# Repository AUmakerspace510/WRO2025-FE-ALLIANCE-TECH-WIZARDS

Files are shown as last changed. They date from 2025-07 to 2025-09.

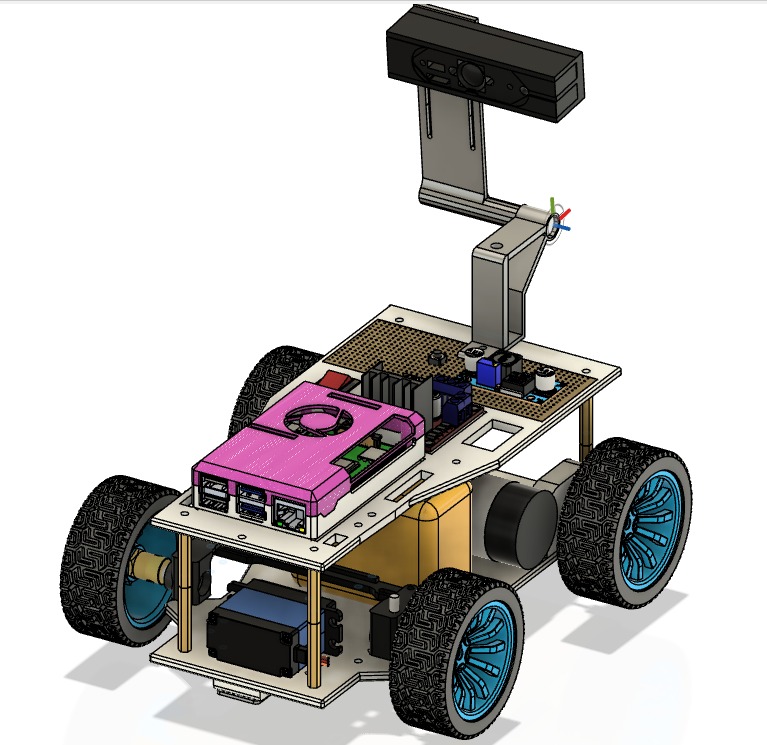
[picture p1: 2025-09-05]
Engineering Factor/3D Design Images/Isometric View.jpg

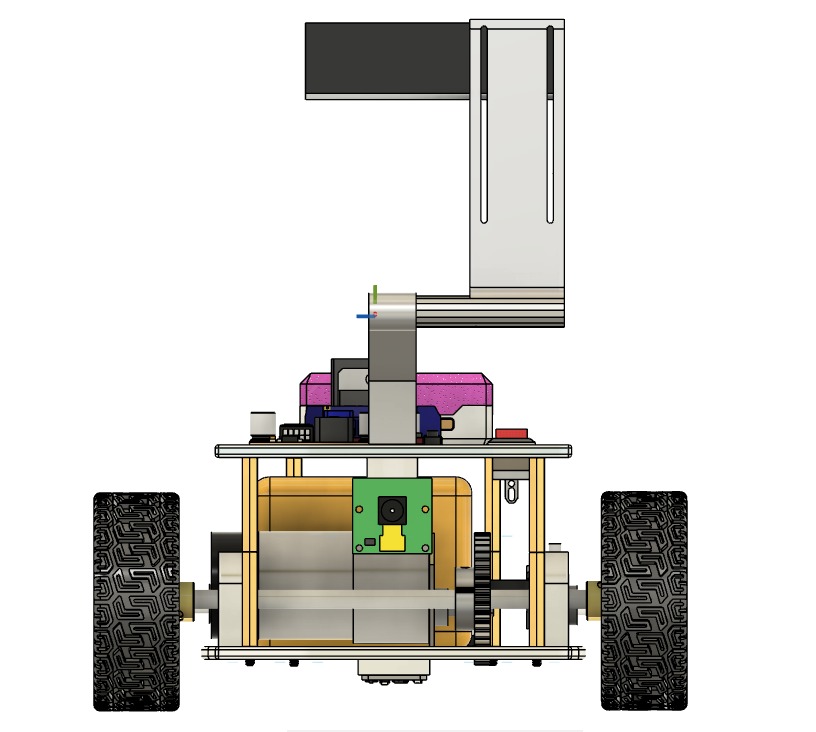
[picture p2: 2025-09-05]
Engineering Factor/3D Design Images/Back View.jpg

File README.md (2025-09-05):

Engineering materials
====

This repository contains engineering materials of a self-driven vehicle's model participating in the WRO Future Engineers competition in the season 202.

## Content

* `t-photos` contains 2 photos of the team (an official one and one funny photo with all team members)
* `v-photos` contains 6 photos of the vehicle (from every side, from top and bottom)
* `video` contains the video.md file with the link to a video where driving demonstration exists
* `schemes` contains one or several schematic diagrams in form of JPEG, PNG or PDF of the electromechanical components illustrating all the elements (electronic components and motors) used in the vehicle and how they connect to each other.
* `src` contains code of control software for all components which were programmed to participate in the competition
* `models` is for the files for models used by 3D printers, laser cutting machines and CNC machines to produce the vehicle elements. If there is nothing to add to this location, the directory can be removed.
* `other` is for other files which can be used to understand how to prepare the vehicle for the competition. It may include documentation how to connect to a SBC/SBM and upload files there, datasets, hardware specifications, communication protocols descriptions etc. If there is nothing to add to this location, the directory can be removed.

<<<<<<< HEAD
=======
_This part must be filled by participants with the technical clarifications about the code: which modules the code consists of, how they are related to the electromechanical components of the vehicle, and what is the process to build/compile/upload the code to the vehicle’s controllers._

## How to prepare the repo based on the template

_Remove this section before the first commit to the repository_

1. Clone this repo by using the `git clone` functionality.
2. Remove `.git` directory
3. [Initialize a new public repository on GitHub](https://github.com/new) by following instructions from "create a new repository on the command line" section (appeared after pressing "Create repository" button).
## readme update
>>>>>>> a575a0db0843b93a4ccf974dce975ff79b570c73

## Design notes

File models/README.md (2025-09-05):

```
# models

This directory contains all the files related to the 3D models and designs for the project. It is organized into several sub-folders for easy navigation and access to different types of files.

## Directory Structure

- `models/`
  - `.stl Files/`: Contains the Stereolithography (.stl) files for 3D printing. These files are the final, ready-to-print models.
  - `3D Design Images/`: Includes various rendered images of the 3D models from different perspectives, as well as a documentation file. These are useful for visualizing the complete design.
  - `parts_dimensions/`: Houses detailed dimensional drawings and images for individual parts. This is crucial for manufacturing, assembly, and reference.

## Contents

### .stl Files

This folder holds the 3D printable files.

- **`WRO_CAMERA HOLDER BASE.stl`**: The base part for the camera holder assembly.
- **`WRO_CAMERA HOLDER.stl`**: The main body of the camera holder, which attaches to the base.
- **`WRO_LOWER CHASIS.stl`**: The bottom section of the robot's chassis.
- **`WRO_UPPER CHASIS.stl`**: The top section of the robot's chassis.

### 3D Design Images

This folder contains rendered images of the complete 3D design.

- **`3D Design Images.docx`**: A document that may contain additional details, descriptions, or a compilation of the images.
- **`Back View.jpg`**: A view of the model from the back.
- **`Camera Holder Isometric View.jpg`**: An isometric view specifically of the camera holder.
- **`Front View.jpg`**: A view of the model from the front.
- **`Isometric View with Labelling.jpg`**: An isometric view with key components labeled for identification.
- **`Isometric View.jpg`**: A general isometric view of the model.
- **`Left View.jpg`**: A view of the model from the left side.
- **`Right View.jpg`**: A view of the model from the right side.
- **`Top Right View.jpg`**: A top-down, slightly angled view of the model.

### parts_dimensions

This folder provides detailed dimensional drawings and images for the individual parts, organized by component.

- **`lower_chassis/`**:
  - `1.png` through `8.png`: A series of images showing various dimensions and features of the lower chassis.
  - `LOWER.png`: A general dimensional drawing of the lower chassis.
  - `PART_LOWER.jpg`: An image of the lower chassis part.

- **`upper_chassis/`**:
  - `1.png` through `7.png` (with `5.png` and `6.png` potentially missing): A series of images showing various dimensions and features of the upper chassis.
  - `PART-11.png`: An additional part-specific image for the upper chassis.

- **`CAMERA_HOLDER.png`**: A dimensional drawing or image for the camera holder part.

---

This README is a general overview. For specific details on each file, refer to its file name and location within the folder structure.
```

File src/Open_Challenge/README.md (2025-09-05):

# WRO2025 FE ALLIANCE TECH WIZARDS - Autonomous Raspberry Pi Robot

This repository contains three core Python files that together enable a Raspberry Pi-powered robot to autonomously follow colored stripes, detect walls, make turns, and stop after completing its course. Below you’ll find detailed documentation for each file.

---

## 1. `masks.py`

### Purpose
Defines color masks for use in image processing. These are LAB color space ranges which help the robot identify different colored stripes (magenta, red, green, blue, orange) and walls (black) in the environment.

### How It Works
- Each mask is a list with two NumPy arrays: the lower and upper bounds for LAB color segmentation.
- These masks are imported in other files and used to isolate specific colors in images captured by the camera.

### Example Usage
Used in the `find_contours` function in `functions.py` and the main loop in `main.py` to detect colored stripes and walls.

### File Reference
```python
import numpy as np

rMagenta = [np.array([22, 150, 50], np.uint8), np.array([200, 200, 150], np.uint8)]
rRed     = [np.array([0, 150, 120], np.uint8), np.array([255, 220, 180], np.uint8)]
rGreen   = [np.array([0, 50, 0], np.uint8), np.array([255, 120, 255], np.uint8)]
rBlue    = [np.array([0, 120, 60], np.uint8), np.array([255, 160, 120], np.uint8)]
rOrange  = [np.array([0, 117, 150], np.uint8), np.array([255, 200, 200], np.uint8)]
rBlack   = [np.array([0, 105, 105], np.uint8), np.array([80, 151, 151], np.uint8)]

lotType = "light"  # 0 for dark purple, 1 for magenta (not used in main code)
```

---

## 2. `functions.py`

### Purpose
Contains all hardware control and image processing functions. This file abstracts GPIO operations and OpenCV image processing into reusable functions.

### Key Functions

- **GPIO Setup:** Configures motor and servo pins, establishes PWM channels.
- **set_motor(speed):** Controls direction and speed of DC motor using L298N.
- **set_servo_angle(angle):** Sets steering angle for the servo motor.
- **write(value):** Unified interface for controlling either steering angle or motor speed.
- **multi_write(sequence):** Executes a list of actions (angles, speeds, delays).
- **stop_car():** Safely stops the robot and resets steering.
- **move_backward_with_mirror(forward_angle, duration, speed):** Reverses with mirrored steering (for advanced maneuvers).
- **display_roi(img, ROIs, color):** Draws rectangles for specified regions of interest (ROIs) on the image, useful for debugging.
- **find_contours(img_lab, lab_range, ROI):** Segments a region of the image for a specific color and finds contours.
- **max_contour(contours, ROI):** Returns area and position of the largest contour found in an ROI.
- **display_variables(variables):** Prints debug information about main variables (e.g., detected wall areas).

### How It Works
- The robot’s hardware (motors/servo) are controlled indirectly by calling these functions from the main loop.
- Image processing functions enable stripe/wall detection, which informs the robot's navigation logic.

### Example Usage
Used by `main.py` to execute movement, steering, and image analysis every frame.

### File Reference
```python
# Example: set_motor(50) moves forward, set_servo_angle(110) steers straight.
# Example: find_contours(img_lab, rBlack, ROI1) gets contours for black walls in left ROI.
```

---

## 3. `main.py`

### Purpose
The main execution file. This script launches the robot’s operational loop: waiting for button press, initializing camera and hardware, detecting stripes and walls, handling turns, counting stripes, and stopping after finishing the course.

### How It Works

1. **Startup:**
   - Waits for the physical button press to start.
   - Initializes camera and sets capture parameters.

2. **ROIs (Regions of Interest):**
   - Defines five ROIs for focused color and wall detection:
     - ROI1: Bottom left (left wall)
     - ROI2: Bottom right (right wall)
     - ROI3: Center (stripe detection)
     - ROI4: Far left (orange turn trigger)
     - ROI5: Far right (blue turn trigger)

3. **Main Loop:**
   - Captures frame, processes in LAB color space.
   - Detects contours for walls and stripes using masks from `masks.py` and functions from `functions.py`.
   - Uses the area of detected contours to maintain wall-following via PID steering logic.
   - Counts stripes (with debounce) and stops after 12 stripes.
   - Handles turns when wall is lost in ROI4/ROI5 (depending on detected color).
   - Displays debug info and stops on user command or course completion.

### Example Usage
Run this file to start the robot after wiring and camera setup.

### File Reference
```python
from functions import *
from masks import rOrange, rBlack, rBlue

# Main loop:
# while True:
#     ret, img = cap.read()
#     img_lab = cv2.cvtColor(img, cv2.COLOR_BGR2Lab)
#     cListLeft = find_contours(img_lab, rBlack, ROI2)
#     ... (see full file for details)
```

---

## Additional Notes

- **Dependencies:** Make sure to install `numpy`, `RPi.GPIO`, and `opencv-python` on your Raspberry Pi.
- **Hardware:** Connect L298N motor driver and a servo as per pin definitions in `functions.py`.
- **Camera:** Any USB webcam compatible with OpenCV should work.
- **Debugging:** Enable `debug = True` in `main.py` to visualize ROIs and variables via OpenCV window.
- **Safety:** The `stop_car()` function is called on exit or after finishing the course to ensure the robot halts safely.

---

## Quick Start

1. Wire up your robot according to the pin definitions in `functions.py`.
2. Place all three files (`masks.py`, `functions.py`, `main.py`) in the same directory.
3. Run `main.py` on your Raspberry Pi.
4. Press the button to start the robot. Watch it follow colored stripes and walls, count stripes, make turns, and stop after the course!

---

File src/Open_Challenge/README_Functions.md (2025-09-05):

# `functions.py` — Hardware and Vision Utilities for Autonomous Robot

This file provides all the core hardware control and image processing functions for your Raspberry Pi robot car.  
It abstracts GPIO operations, PWM setup, DC motor and steering servo commands, and encapsulates reusable vision functions for finding colored contours and displaying debug overlays.

---

## Main Sections

### 1. GPIO and PWM Setup
- Initializes the Raspberry Pi GPIO in BCM mode.
- Sets up output pins for the L298N motor driver (IN1, IN2, ENA) and the servo (SERVO_PIN).
- Configures PWM channels for motor speed and servo position.

---

### 2. Motor Control Functions

#### `set_motor(speed)`
- Controls motor direction and speed via L298N.
- `speed` range: -100 (full reverse) to +100 (full forward), 0 stops.
- Used for every movement or stop command.

#### `CENTER_ANGLE`, `MIN_ANGLE`, `MAX_ANGLE`
- Constants for steering servo position.
- `CENTER_ANGLE` is straight ahead, `MIN_ANGLE` is full left, `MAX_ANGLE` is full right.

#### `set_servo_angle(angle)`
- Sets the servo steering angle, clamped between allowed bounds.
- Converts angle to a PWM duty cycle for accurate positioning.

---

### 3. High-Level Control Functions

#### `write(value)`
- Unified interface for controlling either steering or motor speed.
- If value is in [60,160], sets servo; if in [1000,2000], sets motor speed.

#### `multi_write(sequence)`
- Executes a sequence of actions: steering angles, speeds, or sleep delays.
- Useful for initialization or executing maneuvers.

#### `stop_car()`
- Stops all movement, centers steering, and closes OpenCV windows.
- Called on exit or emergency stop.

#### `move_backward_with_mirror(forward_angle, duration=1, speed=50)`
- Moves the car backward, steering mirrored relative to the last forward angle.
- For advanced reversing maneuvers.

---

### 4. Image Processing Functions

#### `display_roi(img, ROIs, color)`
- Draws rectangles (ROIs) on the image for visualizing detection zones.
- Used for debugging and live feedback in OpenCV window.

#### `find_contours(img_lab, lab_range, ROI)`
- Crops the specified ROI from the LAB image.
- Applies LAB color masking, erodes/dilates to reduce noise.
- Finds and returns contours matching the color mask.

#### `max_contour(contours, ROI)`
- Selects the largest contour in a region, computes area and position.
- Returns `[maxArea, maxX, maxY, mCnt]` for use in steering and wall detection.

#### `display_variables(variables)`
- Prints key debug information (areas, angles, detected colors, etc.) to the console.
- Overwrites previous values for real-time updates.

---

## How This File Is Used

- **Imported in `main.py`** for all hardware and vision operations.
- **Keeps main loop clean:** Complex hardware logic and image analysis are abstracted away for clarity and reuse.
- **Facilitates debugging:** Functions like `display_roi` and `display_variables` enable easy real-time monitoring.

---

## Typical Usage Example

```python
from functions import *

# Set motor speed and direction
set_motor(80)  # Move forward

# Set steering angle
set_servo_angle(110)  # Straight

# Mask and find contours in a camera image
contours = find_contours(img_lab, rOrange, ROI3)
area, x, y, cnt = max_contour(contours, ROI3)

# Stop the car
stop_car()
```

---

## Troubleshooting

- **Servo or motor not responding:** Check GPIO pin assignment and connections.
- **Vision functions not finding contours:** Ensure correct LAB mask values and ROI placement; tune masks with your LAB mask tuner tool.
- **Debugging:** Use `display_roi` and `display_variables` to monitor real-time system state.

---

## References

- [RPi.GPIO documentation](https://sourceforge.net/p/raspberry-gpio-python/wiki/Home/)
- [OpenCV Python reference](https://docs.opencv.org/)
- [L298N Motor Driver](https://www.electronicwings.com/nodemcu/l298n-motor-driver)
- [Servo PWM basics](https://www.raspberrypi-spy.co.uk/2013/07/using-a-servo-with-the-raspberry-pi/)

---

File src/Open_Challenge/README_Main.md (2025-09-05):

# Main Program (`main.py`) — Detailed Documentation

`main.py` contains the main execution loop for the autonomous robot, orchestrating image processing, hardware control, stripe counting, PID steering, and turn handling.  
This file is the entry point for your robot’s run.

---

## Overview of Main Blocks

### 1. **Startup & Initialization**

- **Button Press to Start**  
  Waits for the user to press a physical button (GPIO 26, active LOW) before starting. This ensures safe, controlled startup.

- **Camera Initialization**  
  Sets up the USB camera at 1280x720 resolution, 30 FPS.  
  Checks if the camera opens correctly; exits if not.

---

### 2. **Region of Interest (ROI) Setup**

Defines 5 ROIs (`ROI1` to `ROI5`) as rectangles `[x1, y1, x2, y2]`:
- **ROI1**: Bottom left — left wall detection
- **ROI2**: Bottom right — right wall detection
- **ROI3**: Center — stripe detection
- **ROI4**: Far left — used for orange turn logic
- **ROI5**: Far right — used for blue turn logic

**Purpose:**  
ROIs allow focused contour detection, increasing accuracy and reducing computational load.

---

### 3. **Control Variables**

- **PID parameters:**  
  - `kp` (proportional gain): Controls how strongly the robot reacts to wall area difference.
  - `kd` (derivative gain): Dampens oscillations based on change in area difference.
- **Steering constants:**  
  - `straightConst`: Angle for straight driving.
  - `sharpLeft`, `sharpRight`, `maxLeft`, `maxRight`: Boundaries for sharp turns.
- **Speed:**  
  - Constant value (`speed = 1500`) for motor PWM.

- **Course color detection:**  
  - `activeColor`: Set to `"orange"` or `"blue"` on first detected stripe.
  - `colorCount`: Tracks the number of stripes detected.
  - `debounceSec`: Ensures stripes aren’t double-counted.

---

### 4. **Main Loop — Frame-by-Frame Workflow**

#### a. **Image Capture and Preprocessing**
- Captures a frame.
- Converts frame to LAB color space (more robust to lighting).
- Applies Gaussian blur to reduce noise.

#### b. **Contour Detection**
- Uses functions from `functions.py`:
  - `find_contours()` called for each relevant ROI and color mask.
  - `max_contour()` retrieves area and position for the largest contour.

#### c. **Course Color Selection & Stripe Counting**
- If `activeColor` is not set, assigns based on first detected stripe.
- Stripe count (`colorCount`) incremented only if sufficient time has passed since last detection (`debounceSec` logic).

#### d. **Stopping Logic**
- When 12 stripes detected, robot waits a set period (e.g., 4 seconds) then calls `stop_car()` and exits the loop.

#### e. **Turn Handling**
- **Blue Course:**  
  If left wall is lost in ROI4, rotates left (steers to minimum angle) until left wall is detected in ROI1.
- **Orange Course:**  
  If right wall is lost in ROI5, rotates right (steers to maximum angle) until right wall is detected in ROI2.
- **Purpose:**  
  Allows robot to reliably handle sharp turns and intersections.

#### f. **PID Steering Control**
- Calculates `aDiff = rightArea - leftArea` (difference in wall detection).
- **Angle calculation:**  
  `angle = straightConst + aDiff * kp + (aDiff - prevDiff) * kd`
  - If more right wall detected (positive `aDiff`), robot steers left.
  - If more left wall detected (negative `aDiff`), robot steers right.
- **Sharp Turn Correction:**  
  If wall area drops below threshold, robot applies hard turn until wall reacquired.

#### g. **Debug Display**
- If `debug` is `True`, overlays ROIs on live camera feed and prints key variables.
- Exits if user presses 'q'.

---

### 5. **Cleanup**

- Releases the camera.
- Closes all OpenCV windows.
- Calls `stop_car()` to halt motors and center steering.

---

## How Angle Calculation and PID Steering Work

- **Wall following:**  
  - The robot aims to keep equal wall area in ROI1 and ROI2.
  - PID control smooths and stabilizes steering, reducing oscillations and keeping the robot centered.
- **Turn handling:**  
  - When a wall is lost in turn ROIs, robot rotates in place until the wall is found in main ROI.
  - This avoids getting stuck or missing sharp corners.

---

## Key Functions Used in `main.py`

- `find_contours(img_lab, mask, ROI)`: Finds contours for a color in a region.
- `max_contour(contours, ROI)`: Gets largest detected area and position.
- `write(angle)` & `multi_write([angle, speed])`: Set steering and speed together.
- `stop_car()`: Safely stops robot.

---

## Example Control Flow

1. Start robot with button press.
2. Begin capturing frames, process each for stripes and walls.
3. Use PID to steer between walls.
4. Detect colored stripes and count.
5. Handle turns using dedicated ROIs.
6. Stop after completing course.

---

## Troubleshooting

- If camera doesn’t open, check USB connection or camera index.
- If robot doesn’t move or steer correctly, verify wiring and GPIO pin assignments.
- Use debug mode for live feedback.

---

## References

- [OpenCV LAB Color Processing](https://docs.opencv.org/)
- [RPi.GPIO Library](https://sourceforge.net/p/raspberry-gpio-python/wiki/Home/)
- [L298N Motor Driver Guide](https://www.electronicwings.com/nodemcu/l298n-motor-driver)

---

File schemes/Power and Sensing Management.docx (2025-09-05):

# Power and Sensing Management

### Power Source and Distribution

The robot is powered by a 12V, 4400 mAh Li-ion battery, chosen for its balance between high energy density and portability. The distribution system is optimized for efficiency and safe operation:

- 12V Line (Direct Supply):
  - L298N Motor Driver → 12V DC Motor with Encoder.
- 5V Line (Regulated by XL4015 Buck Converter):
  - Raspberry Pi 5 → Acts as the central controller.
  - Raspberry Pi Camera (5MP Module).
  - LG USB Camera (1080P).
  - Servo Motor.
  - Push Button interface.

The On/Off Switch ensures safe startup and shutdown, while the buck converter provides stable 5V to sensitive components, preventing overload or voltage dips.

Sensing Strategy and Components

#### LG PC Camera (1080P, USB Camera)

- Open Challenge:
  - Detects blue/orange lines to decide rotation direction.
  - Identifies inner/outer black walls to keep the robot centered.
  - Handles wide/narrow corridor detection through zone-based balancing.
  - Manages turns using forward detection (zones A & E).
  - Counts laps (5, 9, 12 detections) and triggers final stop after 3 laps.

#### Raspberry Pi Camera (5MP)

- Obstacle Challenge:
  - Works like a dash cam during parallel parking.
  - Provides accurate visual feedback for parking alignment.
  - Lightweight, directly powered via Pi GPIO.

Novelty and Optimization

- Only two cameras handle all challenges, instead of using multiple ultrasonic or IR sensors.
- This reduces power consumption, wiring complexity, and weight, allowing faster response and smoother navigation.
- Optimized camera training and image processing ensure smooth execution under arena randomness.

Power Consumption Management

- Motors: Draw the largest current (peaks at sharp turns).
- Raspberry Pi + Cameras: Draw stable 5V regulated load (~1.5–2A).
- Servo Motor: Low intermittent load, activated during parking.
- Total System Runtime: The 4400 mAh battery ensures multiple full trial runs before recharge.

Professional Documentation (Wiring & BOM)

The wiring follows professional standards, with clear separation of 12V and 5V lines:

- 12V → L298N → Motors.
- 12V → Buck Converter → 5V → Raspberry Pi → Cameras, Servo, Button.
- Switch + PCB for safe operation and connections.

A detailed Bill of Materials (BOM) lists each component with ratings, ensuring compliance with WRO evaluation standards.

Bill Of Materials (BOM) — summary table

Item (ref) | Qty | Nominal Voltage | Typical Current (A) | Typical Power (W) | Purpose / Notes
12V 4400 mAh battery | 1 | 12 V | — | 52.8 Wh (capacity) | Main energy source (12V, 4.4 Ah → 52.8 Wh)
ON / OFF switch | 1 | 12 V | — | — | Main battery switch
XL4015 step-down (12→5V) | 1 | 12 V in → 5 V out | up to 3 A (set) | up to 15 W out | Supplies Raspberry Pi and 5V peripherals (set current limit safely)
Raspberry Pi 5 (controller) | 1 | 5 V | 1.5 (typical) | 7.5 | Main compute & vision processing — fed from 5V converter
LG USB Camera (1080p) | 1 | 5 V | 0.20 | 1.0 | Primary vision for open round and Obstacle challenge
Raspberry Pi Camera (5MP) | 1 | 5 V | 0.20 | 1.0 | Parking / close-range vision
Servo motor (steering/parking) | 1 | 5 V | 0.50 (avg) | 2.5 | Actuator for parking/steering adjustments
L298N motor driver | 1 | 12 V (motors), 5 V logic | 0.1 (logic) + motor pass-through | 1.2 (logic) + motor power | Motor driver — motors draw directly from 12V
12V DC motor with encoder | 1 | 12 V | 2.0 each (avg running) | 24 each → 48 total | Drive motors — largest power consumers (stall >> average)
Push button | 1 | 5 V | 0.01 | 0.05 | Start/stop or mode switch

Sl. No. | Component Name | Image | Approximate Cost (₹)

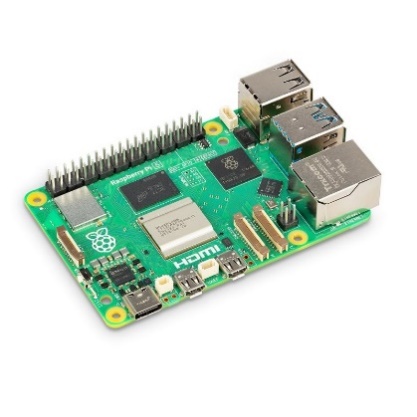
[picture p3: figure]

1. | Raspberry Pi 5 | | 6,000

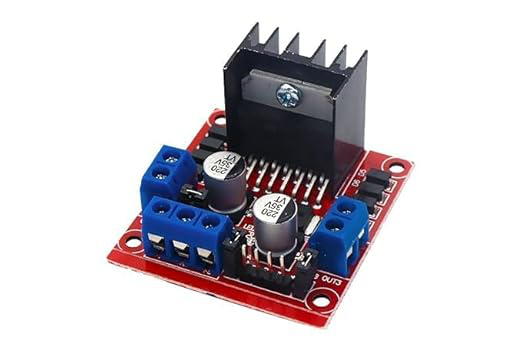
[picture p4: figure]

2. | L298D Motor Driver | | 90

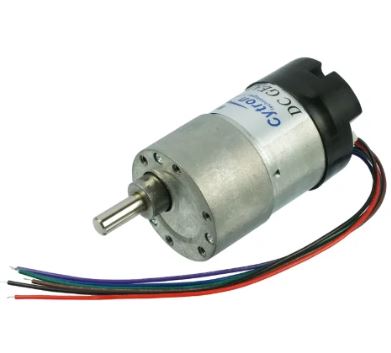
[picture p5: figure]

3. | DC Motor with Encoder | | 700

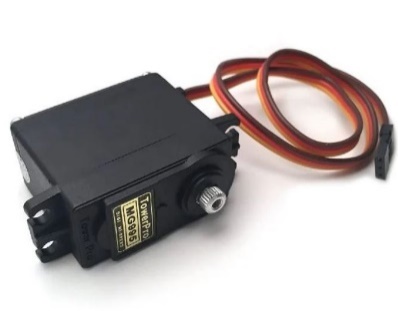
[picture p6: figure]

4. | High Torque Servo Motor | | 350

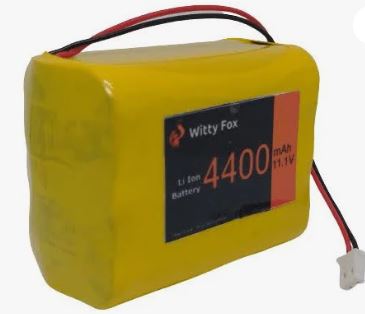
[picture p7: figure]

5. | Lithium-Ion Battery | | 950

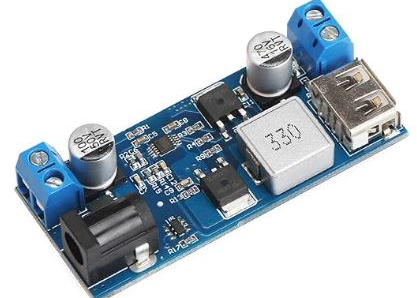
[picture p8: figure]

6. | Buck-to-Buck Converter | | 160

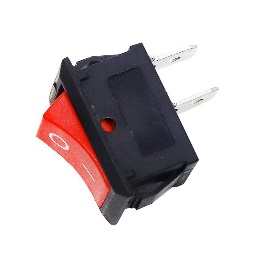
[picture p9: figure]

7. | Red On/Off Switch | | 50 - 100

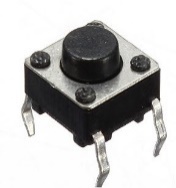
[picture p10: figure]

8. | Push Buttons | | 10 - 30 per button

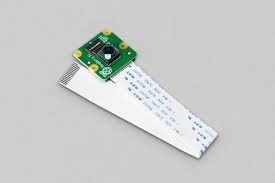
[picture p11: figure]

9. | Raspberry pi Camera | | 350

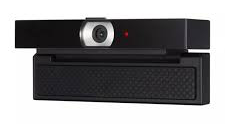
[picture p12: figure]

10 | LG USB Camera 1080P | | 1300

Block Diagram

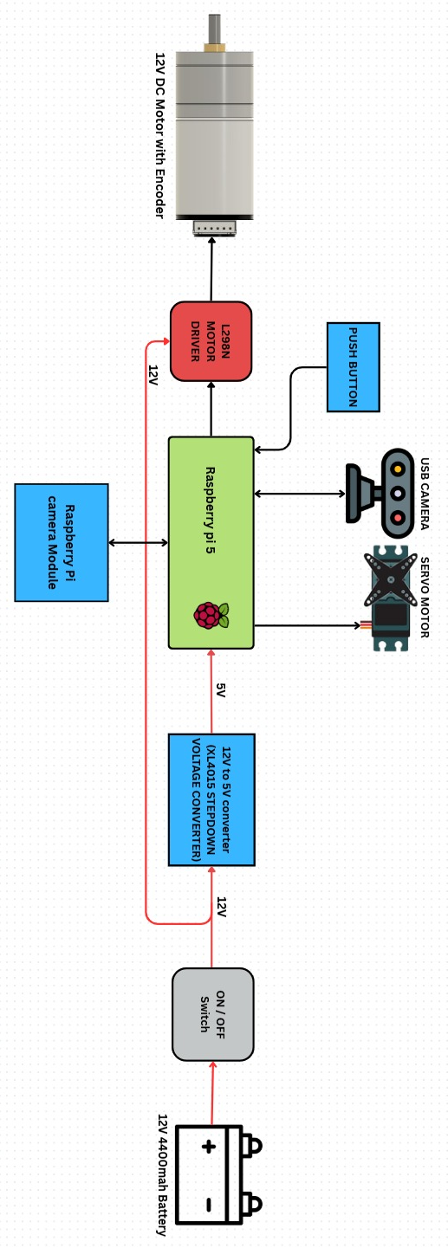
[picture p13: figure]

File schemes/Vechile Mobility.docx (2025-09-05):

Mobility Management

Mobility management in the vehicle primarily focuses on how the bot’s movements are controlled and coordinated based on sensory input and motor actuation. The system architecture is designed to ensure smooth navigation, obstacle avoidance, and accurate response to arena conditions during both the Open Challenge and the Obstacle Challenge.

Sensors and Control Input

The main sensory unit integrated into the bot is the LG PC 1080P camera module, strategically trained according to the gameplay rules of the arena. The vision of this camera is segmented into five regions of interest (ROI) as shown in Figure.1:

- A – Left Wall/ Corridor Detection Zone
- B – Left Zone (White/Black Detection for Turns)
- C – Central Zone (Color Line Detection & Lap Counting)
- D – Right Zone (White/Black Detection for Turns)
- E – Right Wall/ Corridor Detection Zone
1. Two regions (A & E) are dedicated to wall/corridor detection, enabling the bot to remain center-aligned by maintaining equal spacing from the arena boundaries.
2. Two regions (B & D) are used for detecting black/white zones, which assist in identifying turning points, thereby enabling smooth cornering and avoiding collisions.
3. The fifth region © is dedicated to color line detection. The first detected color is considered as the reference, and the bot counts laps based on it until the completion of three laps in the Open Challenge round. This ensures consistent movement either in a clockwise or anticlockwise direction, while ignoring the alternate color line.

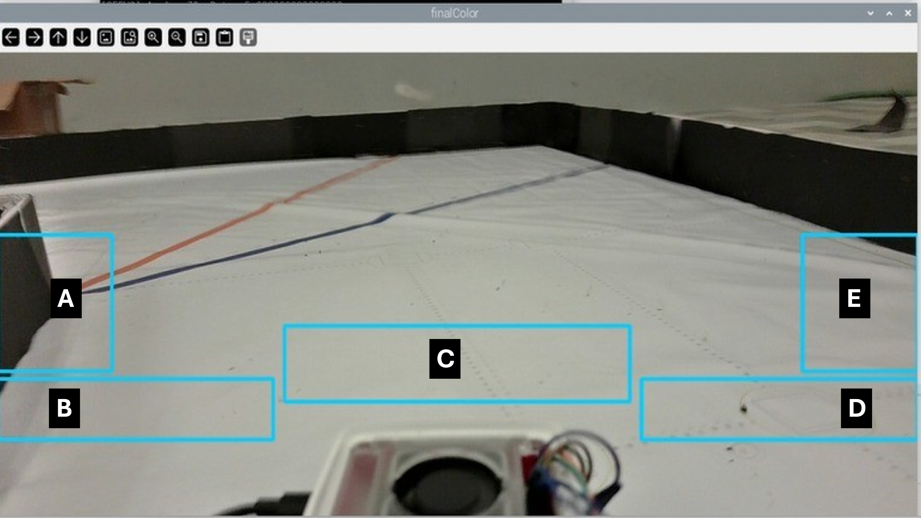
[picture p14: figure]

Fig.1: Camera Vision ROI Segmentation

Additionally, a Raspberry Pi 5 MP camera module is mounted at the rear side of the chassis, specifically for assisting in reverse movement and parking operations.

All sensory inputs from the cameras are processed by the Raspberry Pi 5 (8 GB) microcontroller unit. This controller was selected as it provides the necessary computational power, memory, and accuracy to handle real-time image processing and motor control with minimal discrepancies.

Actuation and Motor Selection

The bot is equipped with two types of motors, carefully chosen to meet torque, speed, and functionality requirements:

1. Steering Motor – High Torque Servo Motor (180° rotation):
  - Used to control the steering mechanism of the bot.
  - Provides precise angular control, ensuring smooth and accurate turning while transitioning between arena sections.
  - High torque capability ensures reliable steering under load and during sharp maneuvers.
2. Driving Motor – DC Motor:
  - Mounted to the rear wheels of the vehicle for forward and reverse locomotion.
  - Anticlockwise rotation → forward movement.
  - Clockwise rotation → backward movement (used mainly for parking in designated zones).
  - Selected for its balance of speed and torque, suitable for stable linear motion within the arena.

The integration of motors with the sensory system ensures that the bot reacts dynamically to the environment, aligning, turning, or reversing as per the detected input.

Chassis Design and Fabrication

The chassis was custom-developed using 3D CAD software to precisely meet the dimensional specifications outlined for the competition challenges. The design process emphasized:

- Compactness and adaptability, enabling the bot to effectively perform in both Open and Obstacle challenge scenarios.
- Systematic placement of all components—including cameras, microcontroller, motors, and wiring—ensuring a clean layout that avoids clutter while maintaining functional interconnections.
- Iterative refinement through multiple design trials and error corrections, resulting in a final optimized structure ready for assembly and deployment.

The finalized model, with all major components labelled, is shown in Figure.2.

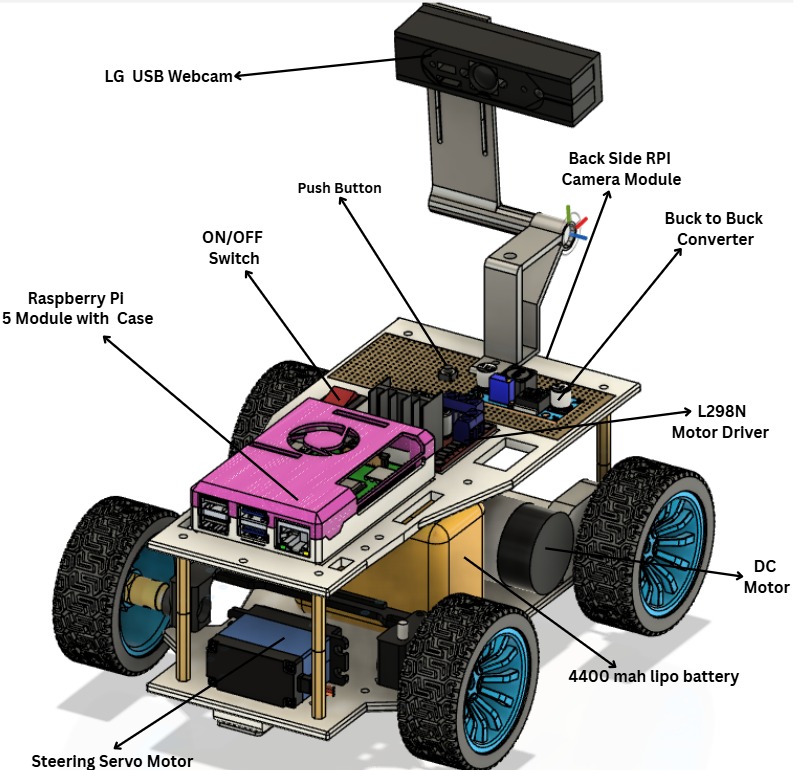
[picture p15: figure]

Fig.2: Assembled 3D Design of the Vehicle with Labelled Components

Once finalized, the chassis and additional mounting parts were fabricated using Fused Deposition Modeling (FDM) 3D printing technology with PLA (Polylactic Acid) filament.

3D Printing Parameters:

- Scaling: 100% (exact design measurements used).
- Infill density: 70% with grid pattern, ensuring strength while minimizing material usage.
- Support structures: Enabled where required, especially for the camera holders.
- Layer thickness: 0.2 mm.
- Nozzle temperature: 215°C.
- Bed temperature: 60°C.

This process ensured that the final chassis structure was rigid, lightweight, and precise, making it well-suited for mounting and supporting all components effectively.

Following the design phase, the chassis and supporting parts were 3D printed using Fused Deposition Modeling (FDM) technology with PLA material, chosen for its strength, lightweight nature, and ease of fabrication. Once fabricated, the electronic and mechanical components were systematically mounted onto the printed chassis, resulting in the fully functional prototype. The completed assembly is illustrated in Figure.3.

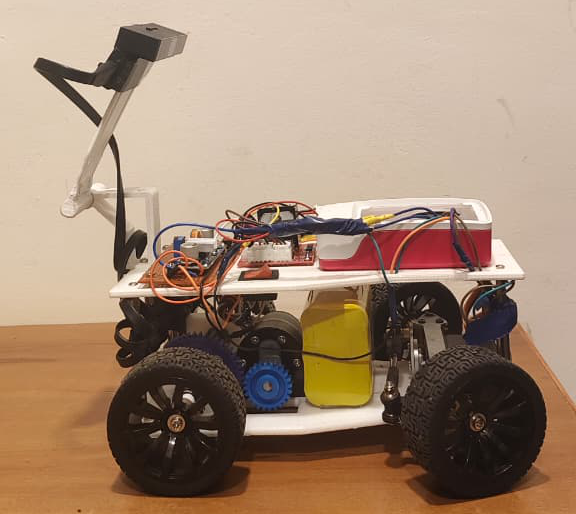
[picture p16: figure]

Fig.3: 3D Printed Chassis with Assembled Components

Summary

By combining a well-trained camera vision system, a powerful Raspberry Pi controller, and carefully selected servo and DC motors, the bot achieves efficient mobility management within the arena. The custom 3D-designed chassis, fabricated using optimized FDM printing parameters, further enhances the bot’s robustness and functionality, ensuring readiness for the Open Challenge and Obstacle Challenge rounds.

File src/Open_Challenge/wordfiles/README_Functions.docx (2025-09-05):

# Detailed Documentation for functions.py and main.py

## functions.py — Function-by-Function Explanation

### GPIO and PWM Setup (Top of File)

## Purpose: Initialize hardware control for DC motor and steering servo using Raspberry Pi’s GPIO pins and PWM channels.

### 1. set_motor(speed)

Purpose: Controls the direction and speed of the DC motor using the L298N driver. Parameters: - speed (int): Range -100 to 100. Positive values move forward, negative backward, zero stops.

Logic: - Sets IN1/IN2 pins for direction. - Sets PWM duty cycle for speed (clamped to 0-100).

When called: Whenever the robot needs to move forward, backward, or stop.

### 2. set_servo_angle(angle)

Purpose: Sets the steering angle for the servo motor. Parameters: - angle (int): Desired steering angle (clamped between 60 left and 160 right).

Logic: - Converts angle to PWM duty cycle. - Updates servo, allows 20ms for movement.

When called: On every steering update.

### 3. write(value)

Purpose: Unified interface for motor and servo control. Parameters: - value (int): If 60-160, sets steering; if 1000-2000, sets motor speed.

Logic: - Calls set_servo_angle or set_motor depending on range.

When called: For simple control commands (in main loop and maneuvers).

### 4. multi_write(sequence)

Purpose: Executes a list of actions: steering, speed, or sleep. Parameters: - sequence (list): List of values; numbers <25 are treated as sleep durations.

Logic: - Loops through sequence, calls write or time.sleep.

When called: For initialization or multi-step maneuvers.

### 5. stop_car()

Purpose: Stops all robot movement and closes OpenCV windows.

Logic: - Sets motor speed to 0. - Centers steering. - Destroys OpenCV windows.

When called: On exit or when robot needs to halt.

### 6. move_backward_with_mirror(forward_angle, duration=1, speed=50)

Purpose: Moves robot backward with steering mirrored to last forward angle (for advanced maneuvers). Parameters: - forward_angle (int): Last used steering angle. - duration (float): Time to move backward. - speed (int): Speed for backward movement.

Logic: - Computes mirrored angle. - Moves backward for the given duration. - Returns steering to forward angle.

When called: For reversing, not used in main loop.

### 7. display_roi(img, ROIs, color)

Purpose: Draws rectangles on the image for visualizing detection zones. Parameters: - img (np.ndarray): The image. - ROIs (list): List of [x1, y1, x2, y2] rectangles. - color (tuple): BGR color for drawing.

Logic: - Draws lines for each ROI.

When called: For debugging with live OpenCV window.

### 8. find_contours(img_lab, lab_range, ROI)

Purpose: Finds contours of a specified color in a region of interest. Parameters: - img_lab (np.ndarray): LAB color space image. - lab_range (list): Lower and upper LAB bounds. - ROI (list): [x1, y1, x2, y2] for cropping.

Logic: - Crops the ROI, applies mask for color, erodes/dilates to reduce noise, finds contours.

When called: Every frame for stripe/wall detection.

### 9. max_contour(contours, ROI)

Purpose: Finds largest contour in a region, returns area and position. Parameters: - contours (list): List of contours. - ROI (list): The detection region.

Logic: - Loops through contours, selects the largest by area. - Computes adjusted position for main loop.

When called: For PID control and turn detection.

### 10. display_variables(variables)

Purpose: Prints current state variables for debugging in console. Parameters: - variables (dict): Name-value pairs.

Logic: - Prints variables, then moves cursor up to overwrite next frame.

When called: If debug=True, prints every frame.

## main.py — Main Control Loop Block Explanations

### Startup Block

- Waits for button press: Robot only starts when user presses the physical button (for safety).
- Initializes camera: Sets up USB webcam (resolution and FPS).

### ROI Setup

- Defines five ROIs: Each is a rectangle [x1, y1, x2, y2].
  - ROI1: Bottom left (left wall)
  - ROI2: Bottom right (right wall)
  - ROI3: Center (stripe detection)
  - ROI4: Far left (orange turn detection)
  - ROI5: Far right (blue turn detection)
- Purpose: Focuses color and contour detection on relevant areas, improving speed and accuracy.

### Control Variables

- PID gains (kp, kd): Tune steering responsiveness.
- Angle limits: straightConst, sharpLeft, sharpRight, maxLeft, maxRight define steering bounds.
- Speed: Sets constant running speed.
- Color logic: Tracks active course color (orange or blue), stripe count, debounce timing.

### Main Loop

Runs every frame:

#### 1. Image Acquisition & Processing

- Captures frame from camera.
- Converts to LAB color space, applies Gaussian blur for noise reduction.

#### 2. Contour Detection

- Calls find_contours for each ROI and color:
  - rBlack in ROI1/ROI2 for walls.
  - rOrange/rBlue in ROI3 for stripes.
- Calls max_contour to get largest detected area (used for PID and turn logic).

#### 3. Active Color Selection

- If activeColor is None, sets to first detected stripe (orange or blue).
- Starts counting stripes only for that color.

#### 4. Stripe Counting (Debounce)

- Increments colorCount only if enough time has passed since last detection (prevents double-counting).

#### 5. Stopping Logic

- When 12 stripes are counted, sets a timer to stop after a few seconds.
- Calls stop_car() and halts loop.

#### 6. Turn Handling

- Blue course: If black wall lost in ROI4 (left), rotates left until wall found in ROI1.
- Orange course: If black wall lost in ROI5 (right), rotates right until wall found in ROI2.
- Uses write(angle) for hard steering.

#### 7. PID Steering Control

- Calculates aDiff: Difference in wall area (right minus left).
  - If right wall more visible, angle increases (steer left).
  - If left wall more visible, angle decreases (steer right).
- Angle calculation:
  - angle = straightConst + (aDiff * kp) + (aDiff - prevDiff) * kd
  - Ensures robot stays centered between walls.
  - Uses clamping: If wall is lost, applies sharp or maximum turn logic.

#### 8. Debug Display

- If debug=True, draws ROIs on image and prints key variables.
- cv2.imshow shows live video, stops on ‘q’ key press.

#### 9. Cleanup

- Releases camera, closes windows, stops motors on exit.

## How Angle Calculation and PID Control Work

- PID wall following:
  - The robot tries to keep both left and right walls equally detected (i.e., equal area in ROI1/ROI2).
  - If right wall area is greater, robot must steer left to center.
  - If left wall area is greater, robot must steer right.
  - PID logic smooths steering to avoid oscillations and over-corrections.
- Turn logic:
  - When a wall is lost in turn ROIs, robot rotates in place in the direction required until wall is reacquired in main wall ROI.
  - This reliably handles sharp corners and intersections.

## Summary

- functions.py provides all hardware and vision utilities.
- main.py orchestrates the robot’s behavior: image analysis, PID steering, turn handling, stripe counting, and stopping.
- ROIs and color masks ensure reliable, efficient vision.
- PID keeps robot centered; turn logic ensures it navigates sharp turns.

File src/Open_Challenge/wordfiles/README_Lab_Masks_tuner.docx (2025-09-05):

# LAB Mask Range Tuner — README

This utility script (lab_mask_tuner.py) helps you discover accurate LAB color ranges for masking colors in your camera feed.
It is especially useful for robotics, vision-based sorting, or any project using OpenCV color segmentation.

## Features

- Live USB camera feed
- Movable region-of-interest (ROI) for focused tuning
- Interactive sliders for LAB lower and upper bounds
- Real-time mask preview
- Shows percent of detected pixels in ROI
- Prints final LAB values when you press ‘q’

## How to Use

1. Connect your USB camera and place a sample of your target color in the ROI area.
2. Run the script: python lab_mask_tuner.py
3. Adjust the sliders in the “Trackbars” window to isolate the target color in the ROI:
  - Move L, A, B sliders for both lower and upper bounds.
  - Watch the “ROI Mask” window — white pixels indicate detected color.
  - The percentage above the ROI shows how much of the area matches your mask.
4. Press ‘q’ to quit. The script prints the final lower and upper LAB values you selected.
5. Copy these values into your color mask definitions (e.g., masks.py in your robot project).

## Example Output

When you press ‘q’, you’ll see something like:

Final Range:
Lower: [40, 130, 80]
Upper: [220, 200, 180]

Use these numbers for your LAB mask in your robotics code.

## Customization

- ROI position: Change roi_x, roi_y, roi_w, roi_h at the top of the script to place the ROI over your sample.
- Camera index: If you have multiple cameras, adjust cv2.VideoCapture(0).

## Tips

- Use in similar lighting conditions as your robot will operate.
- Tune for each color you need (orange, blue, black, etc).
- If the mask is too broad, you may get false positives; if too narrow, some target pixels may be missed.

## Requirements

- Python 3.x
- OpenCV (opencv-python)
- NumPy

Install dependencies with:

pip install opencv-python numpy

## Applications

- Robotics (WRO, FIRST, etc.)
- Color sorting systems
- Industrial automation vision
- Any LAB color segmentation project

## References

- OpenCV Color Spaces (https://docs.opencv.org/4.x/de/d25/imgproc_color_conversions.html)
- LAB Color Tuning (https://docs.opencv.org/4.x/df/d9d/tutorial_py_colorspaces.html)

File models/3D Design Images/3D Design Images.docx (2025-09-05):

Front View

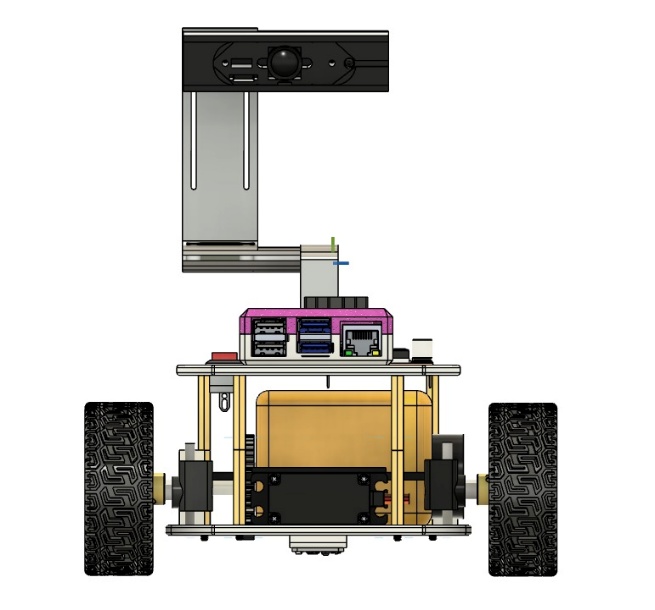
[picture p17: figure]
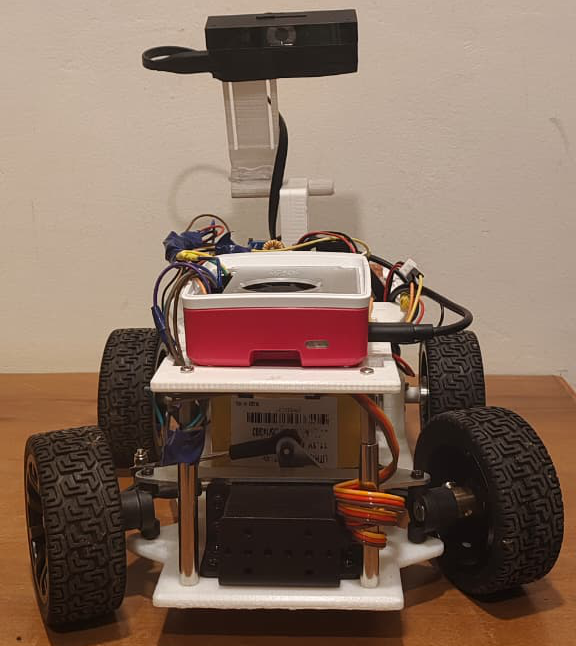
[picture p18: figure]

Back View

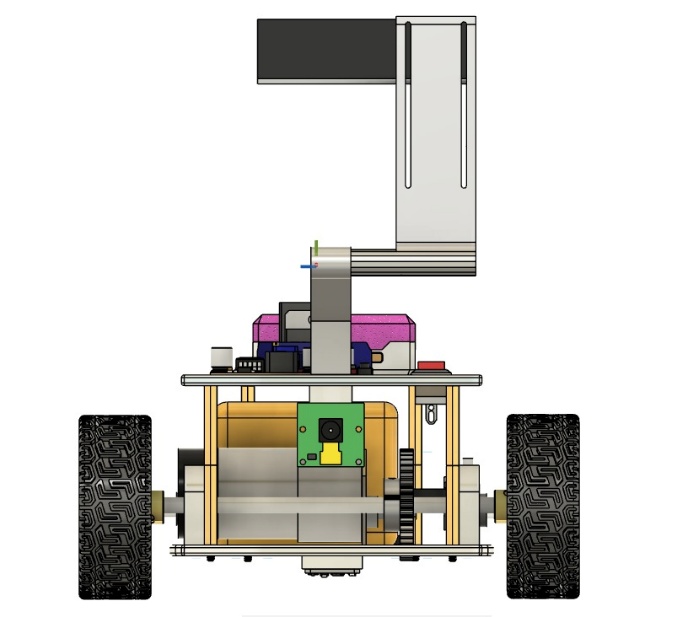
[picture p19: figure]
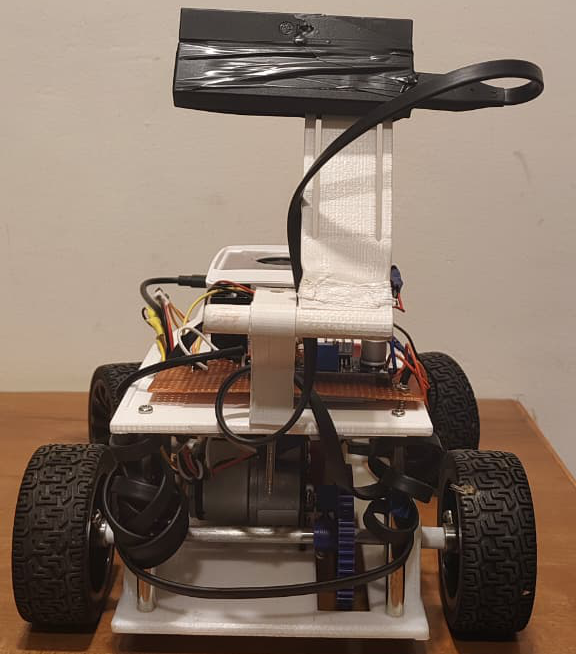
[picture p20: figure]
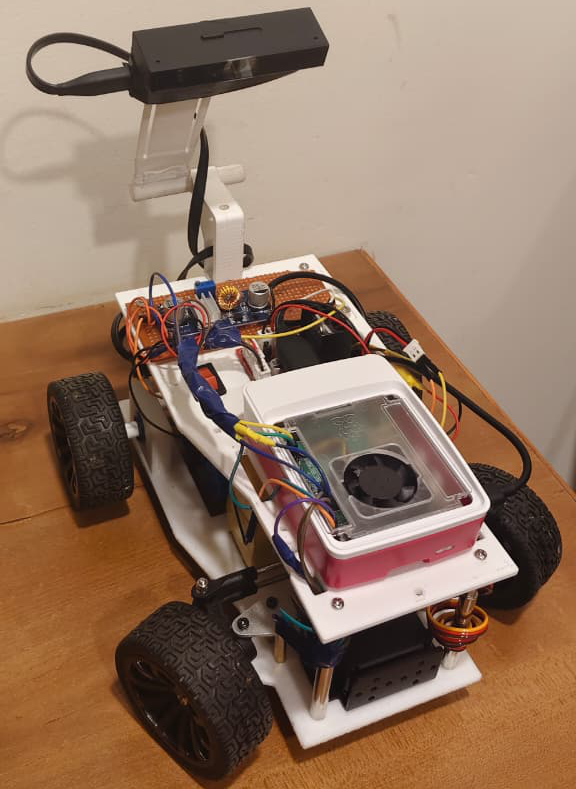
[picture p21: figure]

Isometric view

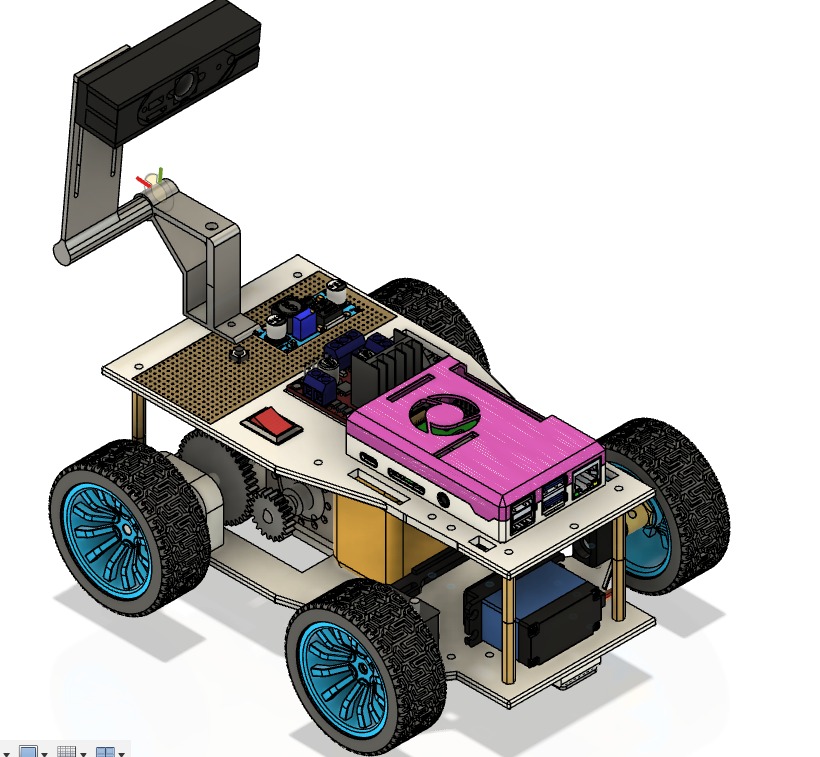
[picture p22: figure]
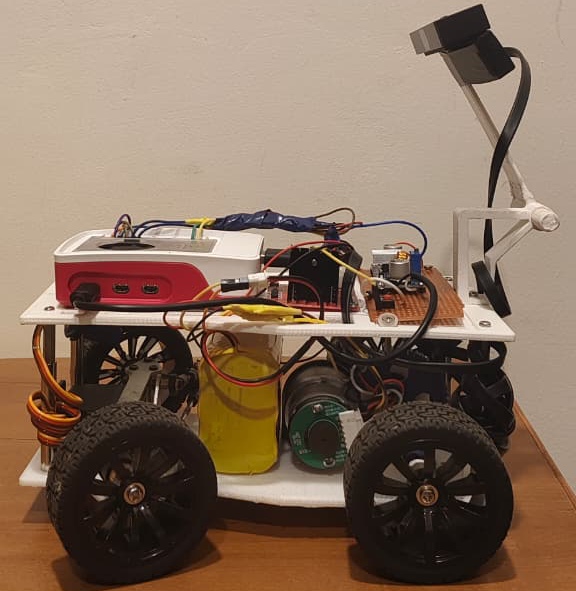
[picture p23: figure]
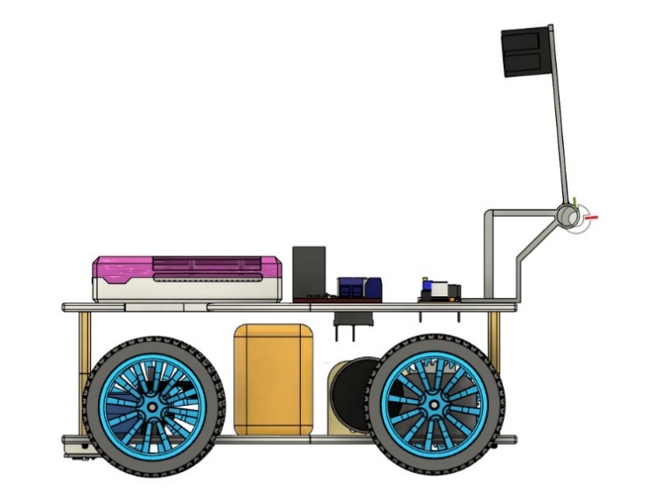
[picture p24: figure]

Left Side View

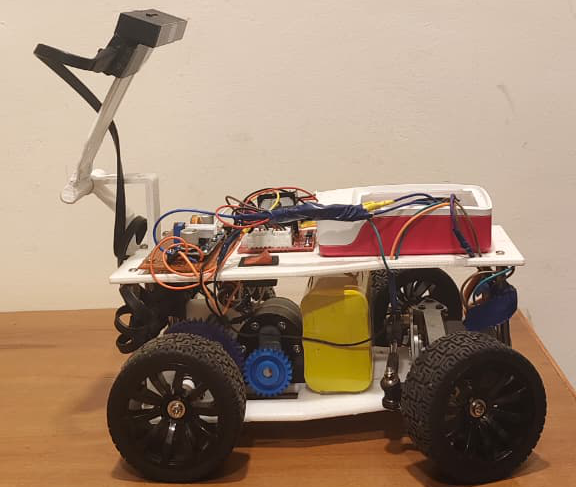
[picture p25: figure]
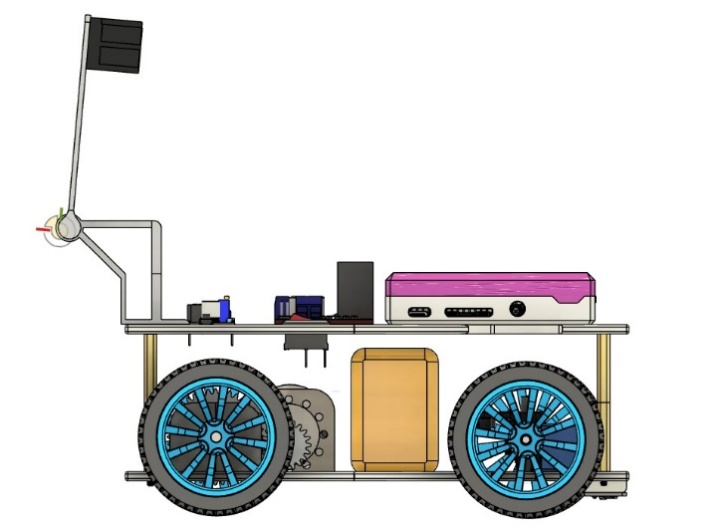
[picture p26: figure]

Right Side View


Top View


Bottom View


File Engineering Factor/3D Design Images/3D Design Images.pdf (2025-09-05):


Front View

Back View


Isometric view

Left Side View

Right Side View


Top View

Bottom View

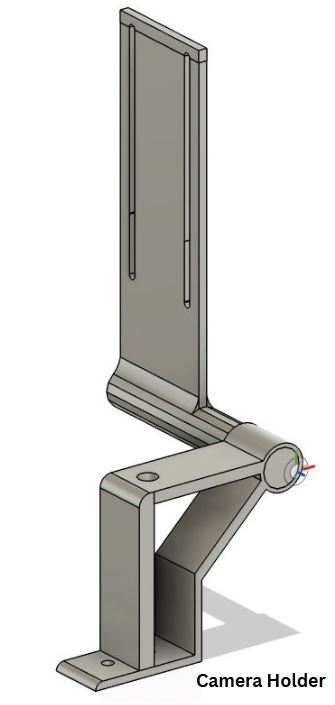
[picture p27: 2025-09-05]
Engineering Factor/3D Design Images/Camera Holder Isometric View.jpg

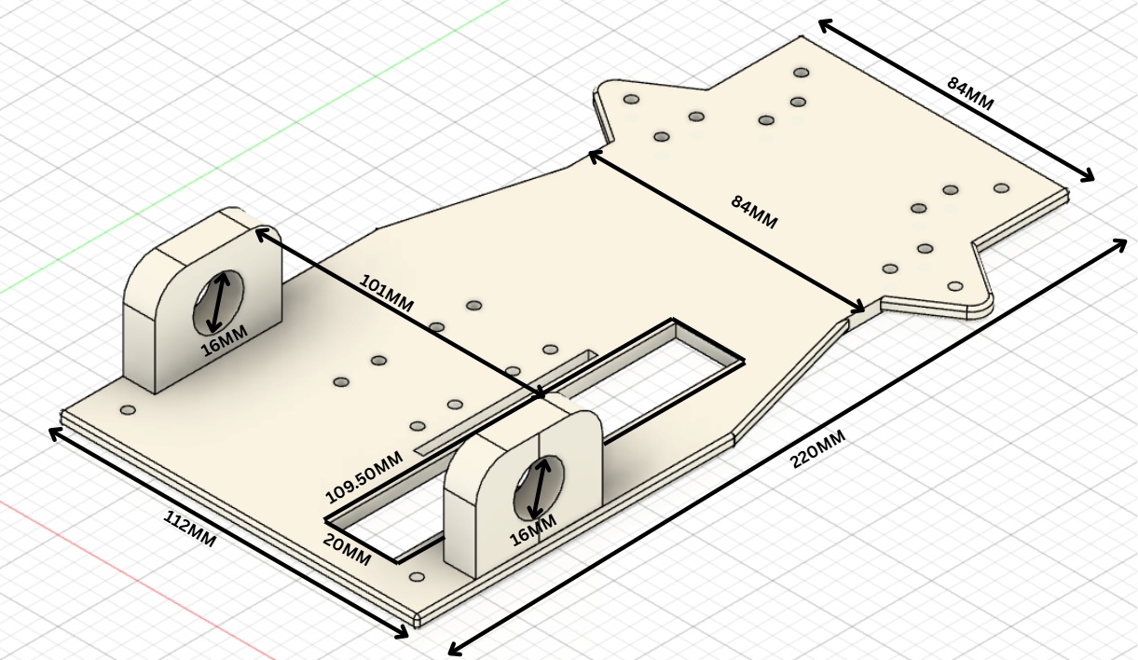
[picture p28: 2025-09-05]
Engineering Factor/parts_dimensions/parts_dimensions/lower_chassis/PART_LOWER.jpg

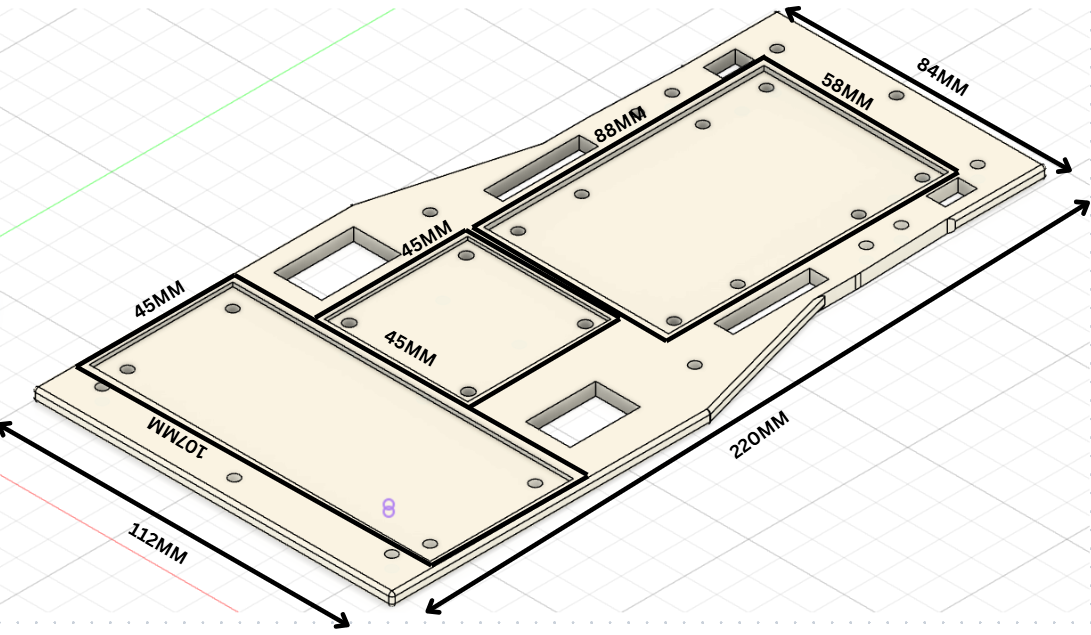
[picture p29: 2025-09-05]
Engineering Factor/parts_dimensions/parts_dimensions/upper_chassis/PART-11.png

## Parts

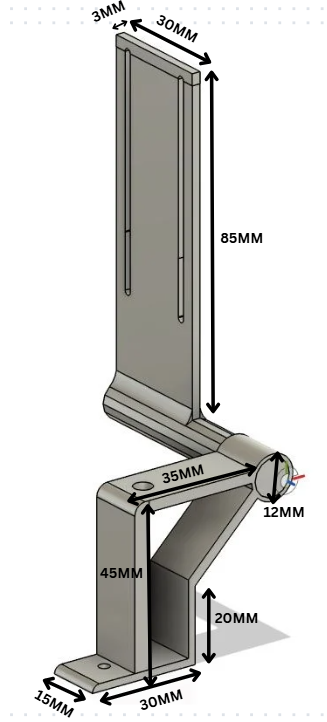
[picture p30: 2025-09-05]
Engineering Factor/parts_dimensions/parts_dimensions/CAMERA_HOLDER.png

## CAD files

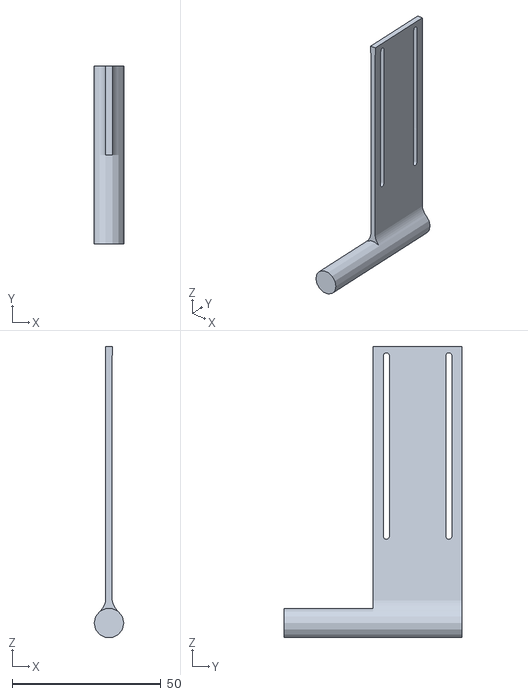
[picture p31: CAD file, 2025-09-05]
Engineering Factor/.stl Files/WRO_CAMERA HOLDER.stl
9.98 x 60.0 x 97.8

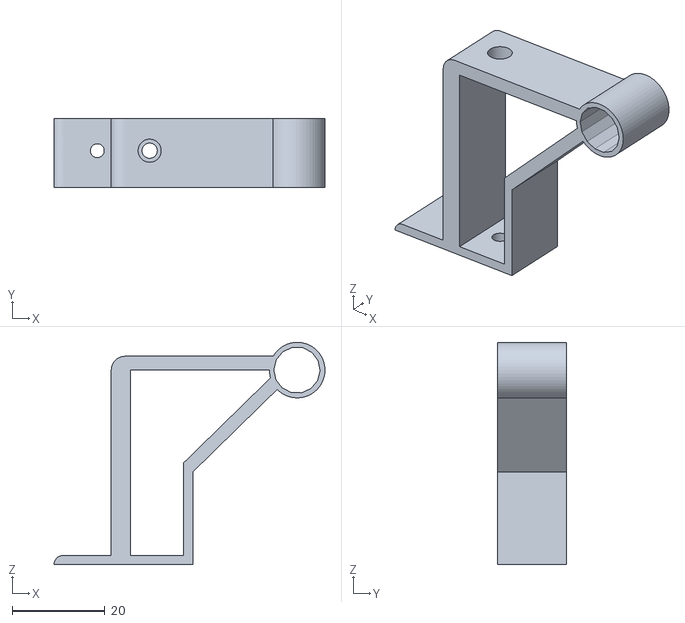
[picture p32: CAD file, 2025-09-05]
Engineering Factor/.stl Files/WRO_CAMERA HOLDER BASE.stl
58.5 x 15.0 x 48.0

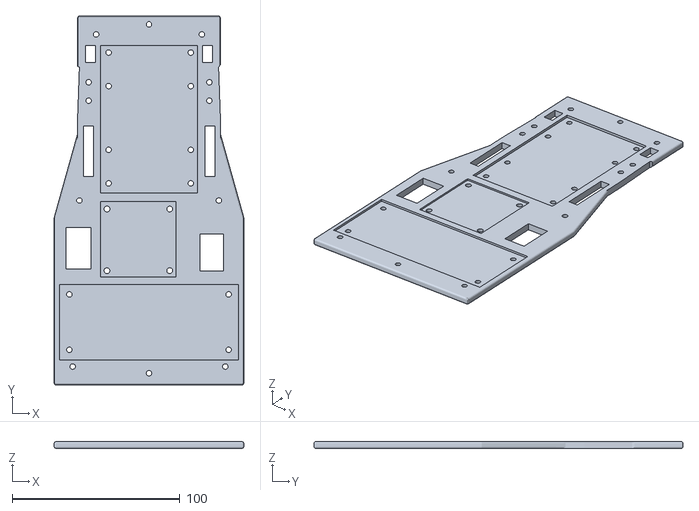
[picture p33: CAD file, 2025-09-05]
Engineering Factor/.stl Files/WRO_UPPER CHASIS.stl
113.0 x 220.0 x 4.00

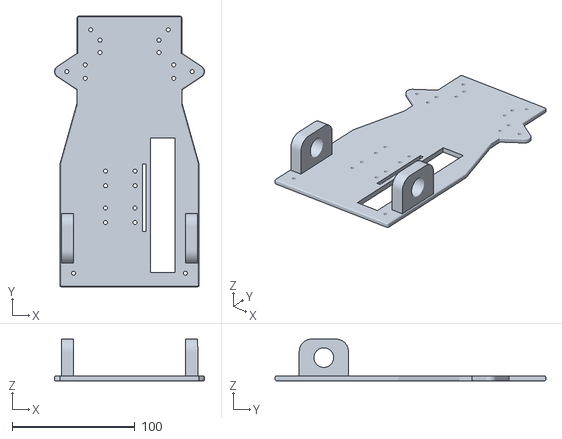
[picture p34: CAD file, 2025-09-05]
Engineering Factor/.stl Files/WRO_LOWER CHASIS.stl
122.0 x 220.0 x 34.0

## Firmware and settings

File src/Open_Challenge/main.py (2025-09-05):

"""
main.py

Main execution file for autonomous robot car.
Initializes hardware and camera, sets up ROIs, runs real-time control loop:
- Detects stripes and walls using color masks and ROIs
- Follows walls using PID control
- Handles turns and stripe counting
- Stops after completing course

Imports:
- functions.py: hardware and image processing utilities
- masks.py: LAB color mask definitions
"""

import sys
sys.path.append('/home/WRO/Desktop/')
import cv2
import RPi.GPIO as GPIO
import numpy as np
import time

from functions import *
from masks import rOrange, rBlack, rBlue

if __name__ == "__main__":
    time.sleep(1)  # allow system to stabilize

    # ---------------- GPIO BUTTON SETUP ----------------
    BUTTON_PIN = 26
    GPIO.setmode(GPIO.BCM)
    GPIO.setup(BUTTON_PIN, GPIO.IN, pull_up_down=GPIO.PUD_UP)  # button active LOW

    print("Waiting for button press to start...")

    # Wait until button is pressed (LOW)
    while GPIO.input(BUTTON_PIN):  
        time.sleep(0.1)

    print("Button pressed! Starting bot...")

    # ---------------- USB CAMERA SETUP ----------------
    cap = cv2.VideoCapture(0)
    cap.set(cv2.CAP_PROP_FRAME_WIDTH, 1280)
    cap.set(cv2.CAP_PROP_FRAME_HEIGHT, 720)
    cap.set(cv2.CAP_PROP_FPS, 30)

    if not cap.isOpened():
        print("Error: Could not open USB camera")
        exit()

    # ---------------- REGIONS OF INTEREST (ROIs) ----------------
    # ROIs define sub-areas in the camera frame for focused detection:
    # Each is [x1, y1, x2, y2] = (left, top, right, bottom)
    ROI1 = [0, 430, 384, 510]       # Bottom left, for left wall (black)
    ROI2 = [896, 430, 1280, 510]    # Bottom right, for right wall (black)
    ROI3 = [400, 360, 880, 460]     # Center stripe detection
    ROI4 = [0, 240, 160, 420]       # Far left (orange turn detection)
    ROI5 = [1120, 240, 1280, 420]   # Far right (blue turn detection)

    # ---------------- CONTROL VARIABLES ----------------
    lTurn = False      # Is a left turn in progress?
    rTurn = False      # Is a right turn in progress?

    # PID parameters for steering control
    kp = 0.15
    kd = 0.004
    straightConst = 110  # Center angle for straight driving

    angle = straightConst
    prevAngle = angle
    tDeviation = 25      # Angle deviation for sharp turns
    sharpRight = straightConst - tDeviation
    sharpLeft = straightConst + tDeviation
    maxRight = straightConst - 50
    maxLeft = straightConst + 50

    speed = 1500        # Motor speed (1000-2000 scale)

    aDiff = 0           # Area difference (right wall - left wall)
    prevDiff = 0

    debug = True        # Enable debug output and OpenCV window
    start = False       # Has the bot started moving?

    # --- COLOR DETECTION LOGIC ---
    activeColor = None      # "orange" or "blue" (course color)
    lastDetectTime = 0      # Last time a stripe was detected
    debounceSec = 5.0       # Stripe detection debounce time (seconds)

    colorCount = 0          # Number of stripes detected
    followEndTime = 0       # Time to stop after 12 stripes

    # ===================== MAIN LOOP =====================
    while True:
        ret, img = cap.read()
        if not ret:
            print("Error: Failed to capture frame")
            break

        # Convert captured frame to LAB color space and blur for noise reduction
        img_lab = cv2.cvtColor(img, cv2.COLOR_BGR2Lab)
        img_lab = cv2.GaussianBlur(img_lab, (7, 7), 0)

        # --- WALL AND STRIPE DETECTION USING ROIs ---
        cListLeft = find_contours(img_lab, rBlack, ROI2)     # Right wall (bottom right ROI)
        cListRight = find_contours(img_lab, rBlack, ROI1)    # Left wall (bottom left ROI)
        cListOrange = find_contours(img_lab, rOrange, ROI3)  # Orange stripe (center ROI)
        cListBlue = find_contours(img_lab, rBlue, ROI3)      # Blue stripe (center ROI)

        leftArea = max_contour(cListLeft, ROI2)[0]   # Area of detected right wall
        rightArea = max_contour(cListRight, ROI1)[0] # Area of detected left wall

        currentTime = time.time()

        # ---------------- ACTIVE COLOR SELECTION ----------------
        # First detected stripe sets the course color (used for turns and counting)
        if activeColor is None:
            if len(cListOrange) > 0:
                activeColor = "orange"
                colorCount = 1
                lastDetectTime = currentTime
                print("Active color set to ORANGE (count=1)")
            elif len(cListBlue) > 0:
                activeColor = "blue"
                colorCount = 1
                lastDetectTime = currentTime
                print("Active color set to BLUE (count=1)")

        # ---------------- STRIPE COUNTING WITH DEBOUNCE ----------------
        # Stripe is counted only if debounce time has passed since last detection
        if activeColor == "orange" and len(cListOrange) > 0 and (currentTime - lastDetectTime) > debounceSec:
            colorCount += 1
            lastDetectTime = currentTime
            print(f"Orange stripe count: {colorCount}")

        elif activeColor == "blue" and len(cListBlue) > 0 and (currentTime - lastDetectTime) > debounceSec:
            colorCount += 1
            lastDetectTime = currentTime
            print(f"Blue stripe count: {colorCount}")

        # ---------------- STOP AFTER 12 STRIPES ----------------
        # When 12 stripes detected, stop after 4 seconds
        if colorCount == 12 and followEndTime == 0:
            followEndTime = currentTime + 7
            print("12 stripes detected! Stopping after 4 seconds...")

        if followEndTime > 0 and currentTime >= followEndTime:
            print("Bot stopped after 12 counts + 4s")
            stop_car()
            set_servo_angle(straightConst)
            break

        # ---------------- TURN HANDLING BASED ON COLOR AND WALL PRESENCE ----------------
        # For blue course: If left ROI (ROI4) loses wall, rotate left until left wall reacquired
        if activeColor == "blue":
            blackROI4 = max_contour(find_contours(img_lab, rBlack, ROI4), ROI4)[0]
            if blackROI4 <= 50:
                print("Blue turn: rotating LEFT until ROI1 sees black")
                startTime = time.time()
                while True:
                    write(70)  # steer hard left
                    ret, img = cap.read()
                    img_lab = cv2.cvtColor(img, cv2.COLOR_BGR2Lab)
                    leftCheck = max_contour(find_contours(img_lab, rBlack, ROI1), ROI1)[0]
                    if leftCheck > 200 or (time.time() - startTime) > 5:
                        print("ROI1 black detected or timeout, resuming PID")
                        break

        # For orange course: If right ROI (ROI5) loses wall, rotate right until right wall reacquired
        elif activeColor == "orange":
            blackROI5 = max_contour(find_contours(img_lab, rBlack, ROI5), ROI5)[0]
            if blackROI5 <= 50:
                print("Orange turn: rotating RIGHT until ROI2 sees black")
                startTime = time.time()
                while True:
                    write(150)  # steer hard right
                    ret, img = cap.read()
                    img_lab = cv2.cvtColor(img, cv2.COLOR_BGR2Lab)
                    rightCheck = max_contour(find_contours(img_lab, rBlack, ROI2), ROI2)[0]
                    if rightCheck > 200 or (time.time() - startTime) > 5:
                        print("ROI2 black detected or timeout, resuming PID")
                        break

        # ---------------- PID WALL FOLLOWING (STEERING CONTROL) ----------------
        # Calculate area difference (right wall - left wall)
        # Positive aDiff: steer left (more right wall detected)
        # Negative aDiff: steer right (more left wall detected)
        aDiff = rightArea - leftArea
        angle = int(max(straightConst + aDiff * kp + (aDiff - prevDiff) * kd, 0))

        # If wall is lost (low area), initiate sharp turn correction
        if leftArea <= 150 and not rTurn:
            lTurn = True
        elif rightArea <= 150 and not lTurn:
            rTurn = True

        # ---------------- INITIAL STARTUP ----------------
        if not start:
            multi_write([angle, speed])  # set steering and speed
            start = True

        # ---------------- STEERING CORRECTION LOGIC ----------------
        if angle != prevAngle:
            if lTurn or rTurn:
                # End sharp turn when wall reacquired
                if (rightArea > 1500 and rTurn) or (leftArea > 1500 and lTurn):
                    lTurn = False
                    rTurn = False
                    prevDiff = 0
                elif lTurn:
                    angle = min(max(angle, sharpLeft), maxLeft)
                elif rTurn:
                    angle = max(min(angle, sharpRight), maxRight)
                write(angle)
                time.sleep(0.01)
            else:
                write(max(min(angle, sharpLeft), sharpRight))
                time.sleep(0.01)

        prevDiff = aDiff
        prevAngle = angle

        # ---------------- DEBUG DISPLAY ----------------
        if debug:
            if cv2.waitKey(1) == ord('q'):
                stop_car()
                break
            img = display_roi(img, [ROI1, ROI2, ROI3, ROI4, ROI5], (255, 204, 0))
            cv2.imshow("finalColor", img)
            variables = {
                "left wall area": leftArea,
                "right wall area": rightArea,
                "Active color": activeColor,
                "Color count": colorCount 
            }
            display_variables(variables)

    # ---------------- CLEANUP ON EXIT ----------------
    cap.release()
    cv2.destroyAllWindows()
    stop_car()
    set_servo_angle(straightConst)

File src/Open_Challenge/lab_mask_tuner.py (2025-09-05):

"""
LAB Mask Range Tuner for Color Detection

This script helps you interactively find the correct LAB color range for masking a color in a camera feed.
It uses OpenCV to display a live feed and a region-of-interest (ROI) mask, with sliders to adjust LAB range.
When you press 'q', the selected LAB bounds are printed for use in your vision code.

Usage:
- Run the script on your Raspberry Pi or computer with a USB camera.
- Move the L, A, B sliders to isolate the target color in the ROI.
- The percentage of detected pixels in the ROI is shown.
- Use the final lower/upper LAB values in your project (e.g., for `masks.py`).

"""

import cv2
import numpy as np

# --- Trackbar callback (does nothing, needed for createTrackbar) ---
def nothing(x):
    pass

# Open USB camera (index 0)
cap = cv2.VideoCapture(0)

# ROI coordinates and size (x, y, width, height)
roi_x, roi_y, roi_w, roi_h = 200, 150, 200, 200   # Adjust for your scene

# Create a window with LAB sliders
cv2.namedWindow("Trackbars")
# Lower LAB bounds
cv2.createTrackbar("L1", "Trackbars", 0, 255, nothing)
cv2.createTrackbar("A1", "Trackbars", 0, 255, nothing)
cv2.createTrackbar("B1", "Trackbars", 0, 255, nothing)
# Upper LAB bounds
cv2.createTrackbar("L2", "Trackbars", 255, 255, nothing)
cv2.createTrackbar("A2", "Trackbars", 255, 255, nothing)
cv2.createTrackbar("B2", "Trackbars", 255, 255, nothing)

while True:
    ret, frame = cap.read()
    if not ret:
        break

    # Extract ROI from frame
    roi = frame[roi_y:roi_y + roi_h, roi_x:roi_x + roi_w]

    # Convert ROI to LAB color space
    lab = cv2.cvtColor(roi, cv2.COLOR_BGR2LAB)

    # Get slider (trackbar) positions for LAB lower and upper bounds
    l1 = cv2.getTrackbarPos("L1", "Trackbars")
    a1 = cv2.getTrackbarPos("A1", "Trackbars")
    b1 = cv2.getTrackbarPos("B1", "Trackbars")
    l2 = cv2.getTrackbarPos("L2", "Trackbars")
    a2 = cv2.getTrackbarPos("A2", "Trackbars")
    b2 = cv2.getTrackbarPos("B2", "Trackbars")

    lower = np.array([l1, a1, b1], dtype=np.uint8)
    upper = np.array([l2, a2, b2], dtype=np.uint8)

    # Apply LAB mask to the ROI
    mask = cv2.inRange(lab, lower, upper)

    # Calculate percentage of masked pixels in ROI
    detected_pixels = cv2.countNonZero(mask)
    total_pixels = roi_w * roi_h
    percent = (detected_pixels / total_pixels) * 100

    # Draw bounding box and percentage reading on main frame
    cv2.rectangle(frame, (roi_x, roi_y), (roi_x + roi_w, roi_y + roi_h), (0, 255, 0), 2)
    cv2.putText(frame, f"Detected: {percent:.1f}%", (roi_x, roi_y - 10),
                cv2.FONT_HERSHEY_SIMPLEX, 0.6, (0, 255, 0), 2)

    # Show live video and mask
    cv2.imshow("Live Feed", frame)
    cv2.imshow("ROI Mask", mask)  # Mask view for tuning

    # Press 'q' to quit and print final LAB values
    if cv2.waitKey(1) & 0xFF == ord('q'):
        print("Final Range:")
        print("Lower:", lower.tolist())
        print("Upper:", upper.tolist())
        break

# Release camera and close windows
cap.release()
cv2.destroyAllWindows()

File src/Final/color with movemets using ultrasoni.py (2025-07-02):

import RPi.GPIO as GPIO
import time
import cv2
import numpy as np
import threading

# ================= GPIO Setup ===================
GPIO.setmode(GPIO.BCM)

# Motor and Servo pins
IN1 = 17
IN2 = 27
ENA = 19
SERVO_PIN = 18

# Ultrasonic pins
TRIG = 5
ECHO = 6

GPIO.setup(IN1, GPIO.OUT)
GPIO.setup(IN2, GPIO.OUT)
GPIO.setup(ENA, GPIO.OUT)
GPIO.setup(SERVO_PIN, GPIO.OUT)
GPIO.setup(TRIG, GPIO.OUT)
GPIO.setup(ECHO, GPIO.IN)

motor_pwm = GPIO.PWM(ENA, 1000)  # Motor speed control
servo_pwm = GPIO.PWM(SERVO_PIN, 50)  # 50 Hz for servo

motor_pwm.start(0)
servo_pwm.start(0)

# ========== Threaded Video Class ==============
class VideoStream:
    def __init__(self, src=0):
        self.cap = cv2.VideoCapture(src)
        if not self.cap.isOpened():
            print("[Error] Cannot open camera")
            GPIO.cleanup()
            exit()
        self.ret, self.frame = self.cap.read()
        self.stopped = False
        threading.Thread(target=self.update, daemon=True).start()

    def update(self):
        while not self.stopped:
            self.ret, self.frame = self.cap.read()

    def read(self):
        return self.ret, self.frame

    def stop(self):
        self.stopped = True
        self.cap.release()

# ================ Functions =================

def set_servo_angle(angle):
    duty = 2 + (angle / 18)
    print(f"[Servo] Setting angle: {angle} -> Duty: {duty:.2f}")
    servo_pwm.ChangeDutyCycle(duty)
    time.sleep(0.3)
    servo_pwm.ChangeDutyCycle(0)

def move_forward(speed=80):
    print(f"[Motor] Moving forward with speed: {speed}")
    GPIO.output(IN1, GPIO.HIGH)
    GPIO.output(IN2, GPIO.LOW)
    motor_pwm.ChangeDutyCycle(speed)

def stop_motor():
    print("[Motor] Stopping")
    GPIO.output(IN1, GPIO.LOW)
    GPIO.output(IN2, GPIO.LOW)
    motor_pwm.ChangeDutyCycle(0)

def get_distance():
    GPIO.output(TRIG, False)
    time.sleep(0.01)

    GPIO.output(TRIG, True)
    time.sleep(0.00001)
    GPIO.output(TRIG, False)

    timeout = time.time() + 0.04  # 40ms timeout

    while GPIO.input(ECHO) == 0:
        if time.time() > timeout:
            return -1
        pulse_start = time.time()

    while GPIO.input(ECHO) == 1:
        if time.time() > timeout:
            return -1
        pulse_end = time.time()

    pulse_duration = pulse_end - pulse_start
    distance = pulse_duration * 17150  # Speed of sound in cm/s

    if distance <= 0 or distance > 300:
        return -1  # Invalid range
    return round(distance, 2)

def average_distance(samples=3):
    distances = []
    for _ in range(samples):
        d = get_distance()
        if d != -1:
            distances.append(d)
        time.sleep(0.01)
    if distances:
        return round(sum(distances) / len(distances), 2)
    else:
        return -1

# ========== Start video capture thread ==========
cap = VideoStream(0)
time.sleep(1)  # Allow camera to warm up

# ========== Motor test before main loop ==========
print("=== Running motor test ===")
move_forward(80)
time.sleep(2)
stop_motor()
time.sleep(1)
print("=== Motor test done ===")

# ========== Main loop variables ==========
state = "normal"
maneuver_start = 0
step = 0

try:
    set_servo_angle(112)
    move_forward(80)

    while True:
        ret, frame = cap.read()

        if not ret:
            print("[Error] Camera frame not received")
            stop_motor()
            break

        hsv = cv2.cvtColor(frame, cv2.COLOR_BGR2HSV)

        # Red detection
        lower_red1 = np.array([0, 120, 70])
        upper_red1 = np.array([10, 255, 255])
        lower_red2 = np.array([170, 120, 70])
        upper_red2 = np.array([180, 255, 255])
        mask_red = cv2.inRange(hsv, lower_red1, upper_red1) + cv2.inRange(hsv, lower_red2, upper_red2)

        # Green detection
        lower_green = np.array([40, 40, 40])
        upper_green = np.array([70, 255, 255])
        mask_green = cv2.inRange(hsv, lower_green, upper_green)

        red_detected = cv2.countNonZero(mask_red) > 5000
        green_detected = cv2.countNonZero(mask_green) > 5000

        current_time = time.time()

        if state == "normal":
            set_servo_angle(112)
            move_forward(80)

            distance = average_distance()
            print(f"[Ultrasonic] Distance: {distance} cm")

            if 0 < distance < 30:
                if red_detected:
                    print("[State] Red detected! Start right-left sequence")
                    state = "red"
                    maneuver_start = current_time
                    step = 0
                elif green_detected:
                    print("[State] Green detected! Start left-right sequence")
                    state = "green"
                    maneuver_start = current_time
                    step = 0

        elif state == "red":
            if step == 0:
                print("[Red] Step 1: Turning right")
                set_servo_angle(142)
                move_forward(80)
                maneuver_start = current_time
                step = 1
            elif step == 1 and current_time - maneuver_start > 1:
                print("[Red] Step 2: Turning left")
                set_servo_angle(82)
                move_forward(80)
                maneuver_start = current_time
                step = 2
            elif step == 2 and current_time - maneuver_start > 1:
                print("[Red] Sequence complete. Returning to normal.")
                state = "normal"

        elif state == "green":
            if step == 0:
                print("[Green] Step 1: Turning left")
                set_servo_angle(72)
                move_forward(100)
                maneuver_start = current_time
                step = 1
            elif step == 1 and current_time - maneuver_start > 1:
                print("[Green] Step 2: Turning right")
                set_servo_angle(152)
                move_forward(80)
                maneuver_start = current_time
                step = 2
            elif step == 2 and current_time - maneuver_start > 1:
                print("[Green] Sequence complete. Returning to normal.")
                state = "normal"

        # Show reduced-size preview window for speed
        resized_frame = cv2.resize(frame, (320, 240))
        cv2.imshow("Live Feed", resized_frame)
        if cv2.waitKey(1) & 0xFF == ord('q'):
            print("[User] Quit command received.")
            break

except KeyboardInterrupt:
    print("[User] Keyboard interrupt received.")

finally:
    print("[Cleanup] Stopping and cleaning up GPIO and camera.")
    stop_motor()
    motor_pwm.stop()
    servo_pwm.stop()
    GPIO.cleanup()
    cap.stop()
    cv2.destroyAllWindows()

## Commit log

2025-07-02 first commit-(02-07-2025)
    [CHASIS_WRO.stl, ULTRASONIC CLAM v1.stl, UPPER_CHASIS_WRO.stl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]
2025-09-05 updated round one and documentation
    [CHASIS_WRO.stl, ULTRASONIC CLAM v1.stl, UPPER_CHASIS_WRO.stl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]
